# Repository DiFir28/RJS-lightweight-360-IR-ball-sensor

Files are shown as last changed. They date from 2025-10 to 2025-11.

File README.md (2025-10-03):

# RJS-lightweight-360-IR-ball-sensor

General view
Top view

## What is it for?

The RJS lightweight rules require the position of the ball emitting IR waves to be determined. 
>The ball's main emission period is 833 microseconds.

Top view

Learn more about [IR ball](https://github.com/robocup-junior/ir-golf-ball).
## Hardware solution
The sensor is a custom PCB. We use as main brain atmega2560. 24 TSSP4038 sensors are located around the circle to read the IR signal.

TSSP4038

## Software solution

Due to the time limit of the ball study period and the need for uniform reading of the circle, at 833 microseconds, data is collected by bytes of pin registers and split into specific pins in a separate cycle. Vectors are constructed based on the sensors that receive the IR signal, with the beginning in the center of the board and the end in each sensor. We calculate a vector equal to the sum of all vectors constructed before the sensors, taking into account the vector on the sensor as many times as the IR signal was detected . The desired angle to the ball will be the angle of the final vector.
The sensor readings are transmitted via the I2C protocol.

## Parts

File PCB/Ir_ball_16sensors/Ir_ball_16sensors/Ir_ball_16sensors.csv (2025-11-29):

Source: | /Users/lonelystrenger/Desktop/роботехника/vsosh/платы /Ir_ball_16sensors/Ir_ball_16sensors.kicad_sch
Date: | Tuesday 20 May 2025 at 19:58:57
Tool: | Eeschema (6.0.0-0)
Generator: | /Applications/KiCad.app/Contents/SharedSupport/plugins/bom_csv_grouped_by_value.py
Component Count: | 55
Individual Components:
Item | Qty | Reference(s) | Value | LibPart | Footprint | Datasheet
 |  | C1 | 0.1uF | Device:C | Capacitor_SMD:C_0603_1608Metric_Pad1.08x0.95mm_HandSolder | ~
 |  | C2 | 0.1uF | Device:C | Capacitor_SMD:C_0603_1608Metric_Pad1.08x0.95mm_HandSolder | ~
 |  | C3 | 47uF 10v | Device:CP1 | Capacitor_Tantalum_SMD:CP_EIA-3216-18_Kemet-A_Pad1.58x1.35mm_HandSolder
 |  | C4 | 0.1uF | Device:C | Capacitor_SMD:C_0603_1608Metric_Pad1.08x0.95mm_HandSolder | ~
 |  | C5 | 0.1uF | Device:C | Capacitor_SMD:C_0603_1608Metric_Pad1.08x0.95mm_HandSolder | ~
 |  | D1 | KP-1608SGC | Device:LED | LED_SMD:LED_0603_1608Metric_Pad1.05x0.95mm_HandSolder | ~
 |  | D2 | WS2812B | LED:WS2812B | LED_SMD:WS2812 | https://cdn-shop.adafruit.com/datasheets/WS2812B.pdf
 |  | D3 | WS2812B | LED:WS2812B | LED_SMD:WS2812 | https://cdn-shop.adafruit.com/datasheets/WS2812B.pdf
 |  | D4 | WS2812B | LED:WS2812B | LED_SMD:WS2812 | https://cdn-shop.adafruit.com/datasheets/WS2812B.pdf
 |  | D5 | WS2812B | LED:WS2812B | LED_SMD:WS2812 | https://cdn-shop.adafruit.com/datasheets/WS2812B.pdf
 |  | D6 | WS2812B | LED:WS2812B | LED_SMD:WS2812 | https://cdn-shop.adafruit.com/datasheets/WS2812B.pdf
 |  | D7 | WS2812B | LED:WS2812B | LED_SMD:WS2812 | https://cdn-shop.adafruit.com/datasheets/WS2812B.pdf
 |  | D8 | WS2812B | LED:WS2812B | LED_SMD:WS2812 | https://cdn-shop.adafruit.com/datasheets/WS2812B.pdf
 |  | D9 | WS2812B | LED:WS2812B | LED_SMD:WS2812 | https://cdn-shop.adafruit.com/datasheets/WS2812B.pdf
 |  | D10 | WS2812B | LED:WS2812B | LED_SMD:WS2812 | https://cdn-shop.adafruit.com/datasheets/WS2812B.pdf
 |  | D11 | WS2812B | LED:WS2812B | LED_SMD:WS2812 | https://cdn-shop.adafruit.com/datasheets/WS2812B.pdf
 |  | D12 | WS2812B | LED:WS2812B | LED_SMD:WS2812 | https://cdn-shop.adafruit.com/datasheets/WS2812B.pdf
 |  | D13 | WS2812B | LED:WS2812B | LED_SMD:WS2812 | https://cdn-shop.adafruit.com/datasheets/WS2812B.pdf
 |  | D14 | WS2812B | LED:WS2812B | LED_SMD:WS2812 | https://cdn-shop.adafruit.com/datasheets/WS2812B.pdf
 |  | D15 | WS2812B | LED:WS2812B | LED_SMD:WS2812 | https://cdn-shop.adafruit.com/datasheets/WS2812B.pdf
 |  | D16 | WS2812B | LED:WS2812B | LED_SMD:WS2812 | https://cdn-shop.adafruit.com/datasheets/WS2812B.pdf
 |  | D17 | WS2812B | LED:WS2812B | LED_SMD:WS2812 | https://cdn-shop.adafruit.com/datasheets/WS2812B.pdf
 |  | J1 | Conn_01x05_Male | Connector:Conn_01x05_Male | Connector_PinHeader_2.54mm:PinHeader_1x05_P2.54mm_Vertical | ~
 |  | J2 | Conn_02x03_Odd_Even | Connector_Generic:Conn_02x03_Odd_Even | Connector_PinSocket_2.54mm:PinSocket_2x03_P2.54mm_Vertical | ~
 |  | J3 | I2c | Connector:Conn_01x04_Female | Connector_PinHeader_2.54mm:PinHeader_1x04_P2.54mm_Vertical | ~
 |  | JP1 | SolderJumper_2_Open | Jumper:SolderJumper_2_Open | Jumper:SolderJumper-2_P1.3mm_Open_TrianglePad1.0x1.5mm | ~
 |  | JP2 | SolderJumper_2_Open | Jumper:SolderJumper_2_Open | Jumper:SolderJumper-2_P1.3mm_Open_TrianglePad1.0x1.5mm | ~
 |  | JP3 | SolderJumper_2_Open | Jumper:SolderJumper_2_Open | Jumper:SolderJumper-2_P1.3mm_Open_TrianglePad1.0x1.5mm | ~
 |  | R1 | 330R | Device:R | Resistor_SMD:R_0603_1608Metric_Pad0.98x0.95mm_HandSolder | ~
 |  | R2 | 10k | Device:R | Resistor_SMD:R_0603_1608Metric_Pad0.98x0.95mm_HandSolder | ~
 |  | R3 | 10k | Device:R | Resistor_SMD:R_0603_1608Metric_Pad0.98x0.95mm_HandSolder | ~
 |  | SW1 | SW_DIP_x02 | Switch:SW_DIP_x02 | Button_Switch_SMD:SW_DIP_SPSTx02_Slide_KingTek_DSHP02TS_W7.62mm_P1.27mm | ~
 |  | SW2 | SW_SPST | Switch:SW_SPST | Button_Switch_SMD:SW_SPST_PTS645 | ~
 |  | TP1 | TestPoint | Connector:TestPoint | TestPoint:TestPoint_Plated_Hole_D3.0mm | ~
 |  | TP2 | TestPoint | Connector:TestPoint | TestPoint:TestPoint_Plated_Hole_D3.0mm | ~
 |  | TP3 | TestPoint | Connector:TestPoint | TestPoint:TestPoint_Plated_Hole_D3.0mm | ~
 |  | TP4 | TestPoint | Connector:TestPoint | TestPoint:TestPoint_Plated_Hole_D3.0mm | ~
 |  | U1 | ATmega328P-M | MCU_Microchip_ATmega:ATmega328P-M | Package_DFN_QFN:QFN-32-1EP_5x5mm_P0.5mm_EP3.1x3.1mm | http://ww1.microchip.com/downloads/en/DeviceDoc/ATmega328_P%20AVR%20MCU%20with%20picoPower%20Technology%20Data%20Sheet%2040001984A.pdf
 |  | U2 | TSSP4038SS1XB | Sensor_Proximity:TSSP58038SS1XB | OptoDevice:Vishay_MINICAST-3Pin | http://www.vishay.com/docs/82740/tssp58038ss1xb.pdf
 |  | U3 | TSSP4038SS1XB | Sensor_Proximity:TSSP58038SS1XB | OptoDevice:Vishay_MINICAST-3Pin | http://www.vishay.com/docs/82740/tssp58038ss1xb.pdf
 |  | U4 | TSSP4038SS1XB | Sensor_Proximity:TSSP58038SS1XB | OptoDevice:Vishay_MINICAST-3Pin | http://www.vishay.com/docs/82740/tssp58038ss1xb.pdf
 |  | U5 | TSSP4038SS1XB | Sensor_Proximity:TSSP58038SS1XB | OptoDevice:Vishay_MINICAST-3Pin | http://www.vishay.com/docs/82740/tssp58038ss1xb.pdf
 |  | U6 | TSSP4038SS1XB | Sensor_Proximity:TSSP58038SS1XB | OptoDevice:Vishay_MINICAST-3Pin | http://www.vishay.com/docs/82740/tssp58038ss1xb.pdf
 |  | U7 | TSSP4038SS1XB | Sensor_Proximity:TSSP58038SS1XB | OptoDevice:Vishay_MINICAST-3Pin | http://www.vishay.com/docs/82740/tssp58038ss1xb.pdf
 |  | U8 | TSSP4038SS1XB | Sensor_Proximity:TSSP58038SS1XB | OptoDevice:Vishay_MINICAST-3Pin | http://www.vishay.com/docs/82740/tssp58038ss1xb.pdf
 |  | U9 | TSSP4038SS1XB | Sensor_Proximity:TSSP58038SS1XB | OptoDevice:Vishay_MINICAST-3Pin | http://www.vishay.com/docs/82740/tssp58038ss1xb.pdf
 |  | U10 | TSSP4038SS1XB | Sensor_Proximity:TSSP58038SS1XB | OptoDevice:Vishay_MINICAST-3Pin | http://www.vishay.com/docs/82740/tssp58038ss1xb.pdf
 |  | U11 | TSSP4038SS1XB | Sensor_Proximity:TSSP58038SS1XB | OptoDevice:Vishay_MINICAST-3Pin | http://www.vishay.com/docs/82740/tssp58038ss1xb.pdf
 |  | U12 | TSSP4038SS1XB | Sensor_Proximity:TSSP58038SS1XB | OptoDevice:Vishay_MINICAST-3Pin | http://www.vishay.com/docs/82740/tssp58038ss1xb.pdf
 |  | U13 | TSSP4038SS1XB | Sensor_Proximity:TSSP58038SS1XB | OptoDevice:Vishay_MINICAST-3Pin | http://www.vishay.com/docs/82740/tssp58038ss1xb.pdf
 |  | U14 | TSSP4038SS1XB | Sensor_Proximity:TSSP58038SS1XB | OptoDevice:Vishay_MINICAST-3Pin | http://www.vishay.com/docs/82740/tssp58038ss1xb.pdf
 |  | U15 | TSSP4038SS1XB | Sensor_Proximity:TSSP58038SS1XB | OptoDevice:Vishay_MINICAST-3Pin | http://www.vishay.com/docs/82740/tssp58038ss1xb.pdf
 |  | U16 | TSSP4038SS1XB | Sensor_Proximity:TSSP58038SS1XB | OptoDevice:Vishay_MINICAST-3Pin | http://www.vishay.com/docs/82740/tssp58038ss1xb.pdf
 |  | U17 | TSSP4038SS1XB | Sensor_Proximity:TSSP58038SS1XB | OptoDevice:Vishay_MINICAST-3Pin | http://www.vishay.com/docs/82740/tssp58038ss1xb.pdf
 |  | Y1 | Resonator | Device:Resonator_Small | Crystal:Resonator_SMD_Murata_CSTxExxV-3Pin_3.0x1.1mm_HandSoldering | ~
Collated Components:
Item | Qty | Reference(s) | Value | LibPart | Footprint | Datasheet
1 | 4 | C1, C2, C4, C5 | 0.1uF | Device:C | Capacitor_SMD:C_0603_1608Metric_Pad1.08x0.95mm_HandSolder | ~
2 | 1 | C3 | 47uF 10v | Device:CP1 | Capacitor_Tantalum_SMD:CP_EIA-3216-18_Kemet-A_Pad1.58x1.35mm_HandSolder
3 | 1 | D1 | KP-1608SGC | Device:LED | LED_SMD:LED_0603_1608Metric_Pad1.05x0.95mm_HandSolder | ~
4 | 16 | D2, D3, D4, D5, D6, D7, D8, D9, D10, D11, D12, D13, D14, D15, D16, D17 | WS2812B | LED:WS2812B | LED_SMD:WS2812 | https://cdn-shop.adafruit.com/datasheets/WS2812B.pdf
5 | 1 | J1 | Conn_01x05_Male | Connector:Conn_01x05_Male | Connector_PinHeader_2.54mm:PinHeader_1x05_P2.54mm_Vertical | ~
6 | 1 | J2 | Conn_02x03_Odd_Even | Connector_Generic:Conn_02x03_Odd_Even | Connector_PinSocket_2.54mm:PinSocket_2x03_P2.54mm_Vertical | ~
7 | 1 | J3 | I2c | Connector:Conn_01x04_Female | Connector_PinHeader_2.54mm:PinHeader_1x04_P2.54mm_Vertical | ~
8 | 3 | JP1, JP2, JP3 | SolderJumper_2_Open | Jumper:SolderJumper_2_Open | Jumper:SolderJumper-2_P1.3mm_Open_TrianglePad1.0x1.5mm | ~
9 | 1 | R1 | 330R | Device:R | Resistor_SMD:R_0603_1608Metric_Pad0.98x0.95mm_HandSolder | ~
10 | 2 | R2, R3 | 10k | Device:R | Resistor_SMD:R_0603_1608Metric_Pad0.98x0.95mm_HandSolder | ~
11 | 1 | SW1 | SW_DIP_x02 | Switch:SW_DIP_x02 | Button_Switch_SMD:SW_DIP_SPSTx02_Slide_KingTek_DSHP02TS_W7.62mm_P1.27mm | ~
12 | 1 | SW2 | SW_SPST | Switch:SW_SPST | Button_Switch_SMD:SW_SPST_PTS645 | ~
13 | 4 | TP1, TP2, TP3, TP4 | TestPoint | Connector:TestPoint | TestPoint:TestPoint_Plated_Hole_D3.0mm | ~
14 | 1 | U1 | ATmega328P-M | MCU_Microchip_ATmega:ATmega328P-M | Package_DFN_QFN:QFN-32-1EP_5x5mm_P0.5mm_EP3.1x3.1mm | http://ww1.microchip.com/downloads/en/DeviceDoc/ATmega328_P%20AVR%20MCU%20with%20picoPower%20Technology%20Data%20Sheet%2040001984A.pdf
15 | 16 | U2, U3, U4, U5, U6, U7, U8, U9, U10, U11, U12, U13, U14, U15, U16, U17 | TSSP4038SS1XB | Sensor_Proximity:TSSP58038SS1XB | OptoDevice:Vishay_MINICAST-3Pin | http://www.vishay.com/docs/82740/tssp58038ss1xb.pdf
16 | 1 | Y1 | Resonator | Device:Resonator_Small | Crystal:Resonator_SMD_Murata_CSTxExxV-3Pin_3.0x1.1mm_HandSoldering | ~

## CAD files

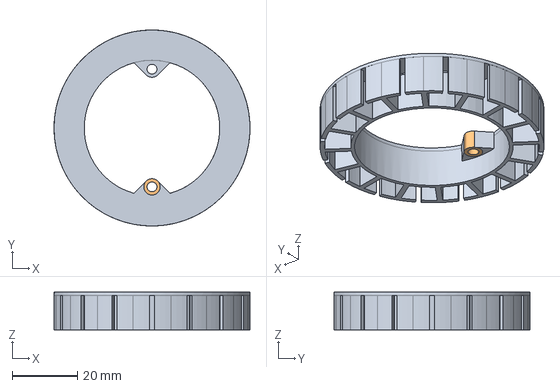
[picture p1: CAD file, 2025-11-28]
3D_models/Ir_ball_16sensors.step
60.0 x 60.0 x 11.6 mm

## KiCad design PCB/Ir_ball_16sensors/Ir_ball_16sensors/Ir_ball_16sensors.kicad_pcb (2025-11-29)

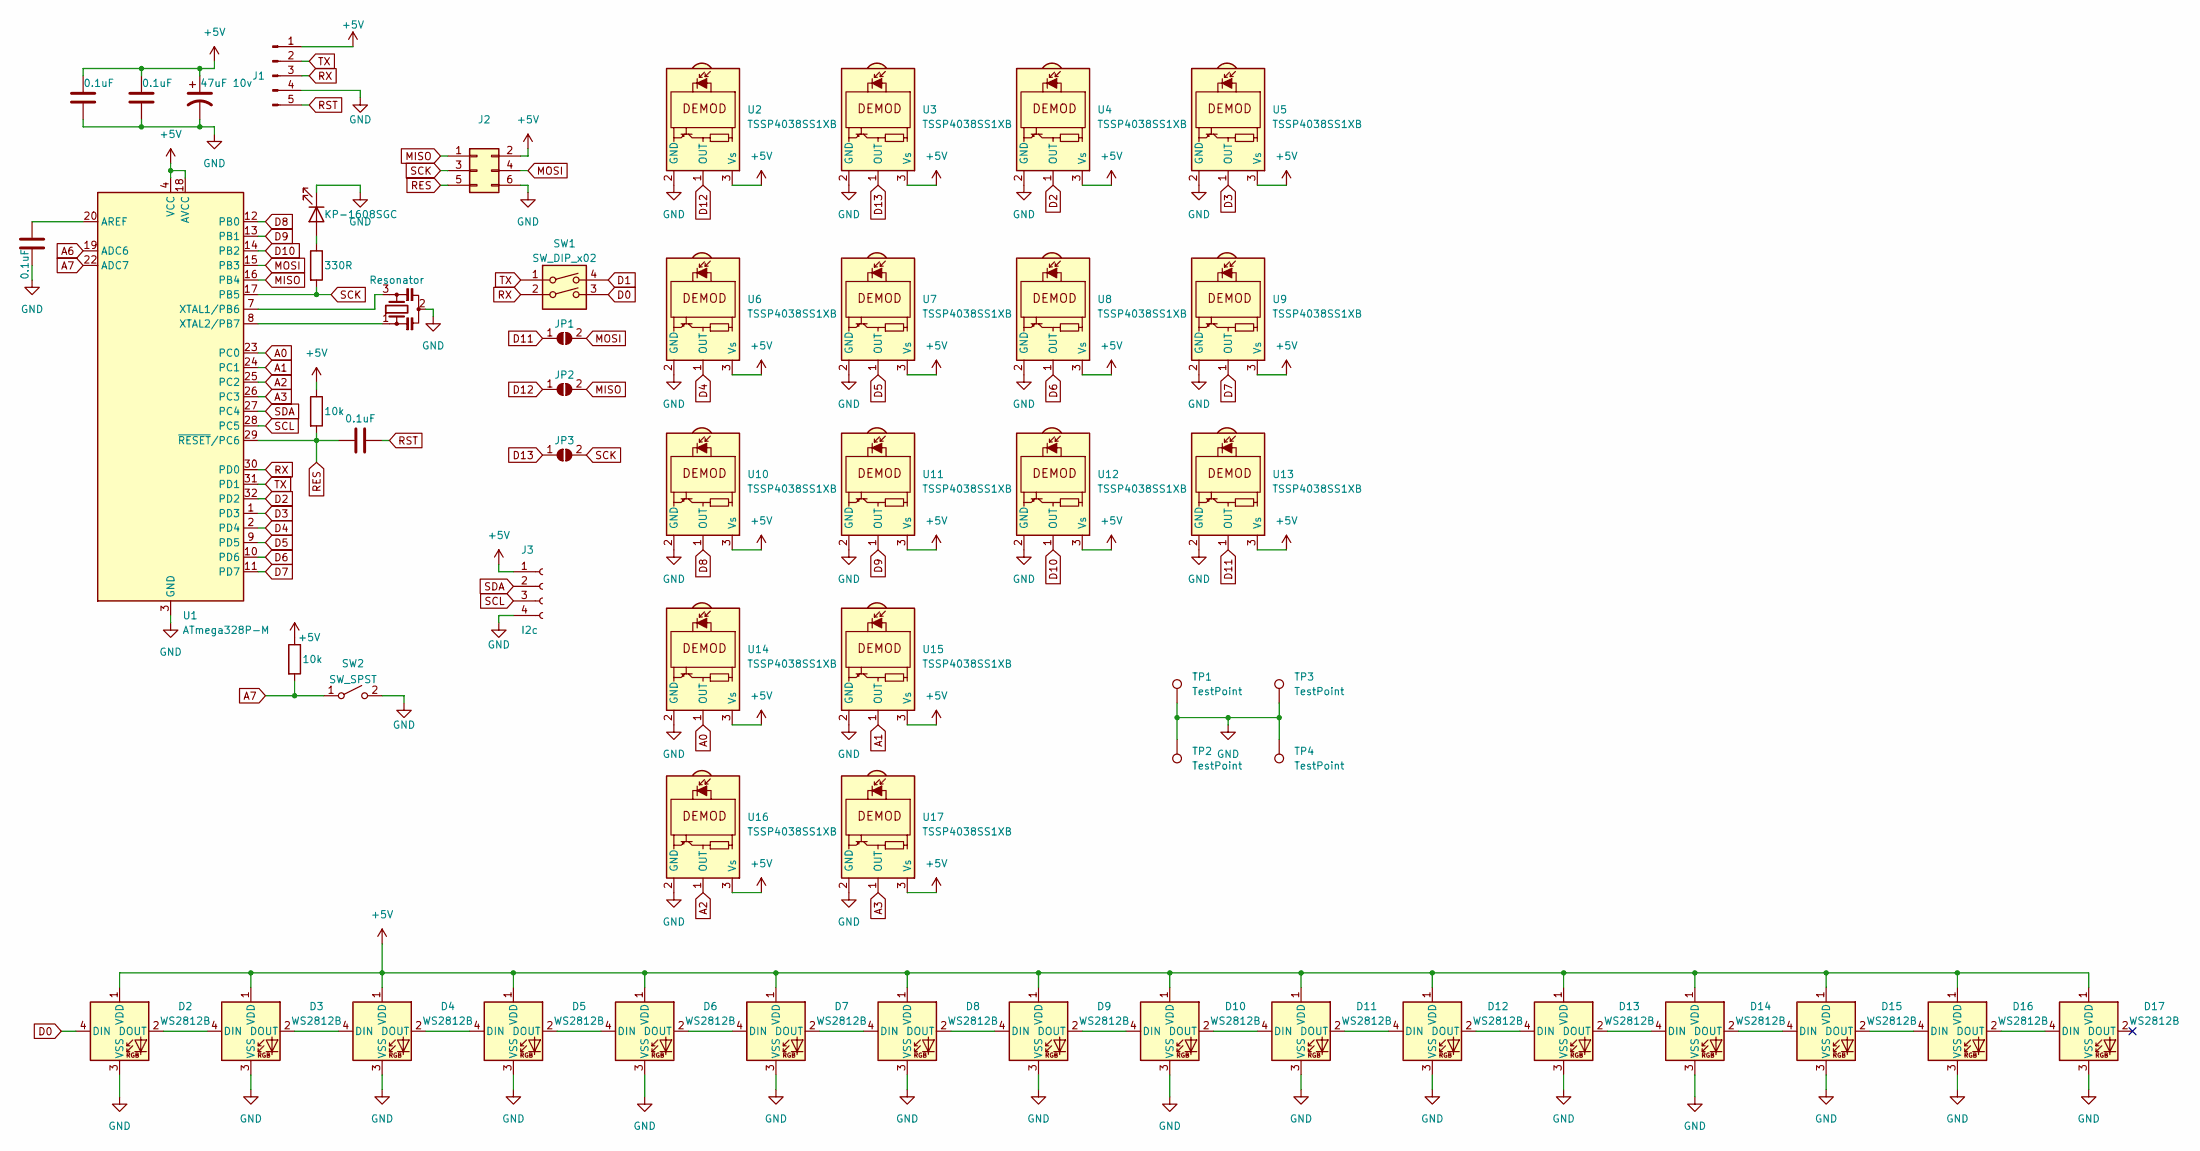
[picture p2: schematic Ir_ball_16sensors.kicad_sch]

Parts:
C1, C2, C4, C5: 0.1uF; C_0603_1608Metric_Pad1.08x0.95mm_HandSolder
C3: 47uF 10v; CP_EIA-3216-18_Kemet-A_Pad1.58x1.35mm_HandSolder
D1: KP-1608SGC; LED_0603_1608Metric_Pad1.05x0.95mm_HandSolder
D2, D3, D4, D5, D6, D7, D8, D9, D10, D11, D12, D13, D14, D15, D16, D17: WS2812B; WS2812
J1: Conn_01x05_Male; PinHeader_1x05_P2.54mm_Vertical
J2: Conn_02x03_Odd_Even; PinSocket_2x03_P2.54mm_Vertical
J3: I2c; PinHeader_1x04_P2.54mm_Vertical
JP1, JP2, JP3: SolderJumper_2_Open; SolderJumper-2_P1.3mm_Open_TrianglePad1.0x1.5mm
R1: 330R; R_0603_1608Metric_Pad0.98x0.95mm_HandSolder
R2, R3: 10k; R_0603_1608Metric_Pad0.98x0.95mm_HandSolder
SW1: SW_DIP_x02; SW_DIP_SPSTx02_Slide_KingTek_DSHP02TS_W7.62mm_P1.27mm
SW2: SW_SPST; SW_SPST_PTS645
TP1, TP2, TP3, TP4: TestPoint; TestPoint_Plated_Hole_D3.0mm
U1: ATmega328P-M; QFN-32-1EP_5x5mm_P0.5mm_EP3.1x3.1mm
U2, U3, U4, U5, U6, U7, U8, U9, U10, U11, U12, U13, U14, U15, U16, U17: TSSP4038SS1XB; Vishay_MINICAST-3Pin
Y1: Resonator; Resonator_SMD_Murata_CSTxExxV-3Pin_3.0x1.1mm_HandSoldering

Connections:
+5V: C1.2, C2.2, C3.1, D2.1 (VDD), D3.1 (VDD), D4.1 (VDD), D5.1 (VDD), D6.1 (VDD), D7.1 (VDD), D8.1 (VDD), D9.1 (VDD), D10.1 (VDD), D11.1 (VDD), D12.1 (VDD), D13.1 (VDD), D14.1 (VDD), D15.1 (VDD), D16.1 (VDD), D17.1 (VDD), J1.1, J2.2, J3.1, R2.1, R3.1, U1.4 (VCC), U1.6 (VCC), U1.18 (AVCC), U2.3 (Vs), U3.3 (Vs), U4.3 (Vs), U5.3 (Vs), U6.3 (Vs), U7.3 (Vs), U8.3 (Vs), U9.3 (Vs), U10.3 (Vs), U11.3 (Vs), U12.3 (Vs), U13.3 (Vs), U14.3 (Vs), U15.3 (Vs), U16.3 (Vs), U17.3 (Vs)
A0: U1.23 (PC0), U14.1 (OUT)
A1: U1.24 (PC1), U15.1 (OUT)
A2: U1.25 (PC2), U16.1 (OUT)
A3: U1.26 (PC3), U17.1 (OUT)
A6: U1.19 (ADC6)
A7: R3.2, SW2.1 (A), U1.22 (ADC7)
D0: D2.4 (DIN), SW1.3
D1: SW1.4
D2: U1.32 (PD2), U4.1 (OUT)
D3: U1.1 (PD3), U5.1 (OUT)
D4: U1.2 (PD4), U6.1 (OUT)
D5: U1.9 (PD5), U7.1 (OUT)
D6: U1.10 (PD6), U8.1 (OUT)
D7: U1.11 (PD7), U9.1 (OUT)
D8: U1.12 (PB0), U10.1 (OUT)
D9: U1.13 (PB1), U11.1 (OUT)
D10: U1.14 (PB2), U12.1 (OUT)
D11: JP1.1 (A), U13.1 (OUT)
D12: JP2.1 (A), U2.1 (OUT)
D13: JP3.1 (A), U3.1 (OUT)
GND: C1.1, C2.1, C3.2, C5.1, D1.1 (K), D2.3 (VSS), D3.3 (VSS), D4.3 (VSS), D5.3 (VSS), D6.3 (VSS), D7.3 (VSS), D8.3 (VSS), D9.3 (VSS), D10.3 (VSS), D11.3 (VSS), D12.3 (VSS), D13.3 (VSS), D14.3 (VSS), D15.3 (VSS), D16.3 (VSS), D17.3 (VSS), J1.4, J2.6, J3.4, SW2.2 (B), TP1.1, TP2.1, TP3.1, TP4.1, U1.3 (GND), U1.5 (GND), U1.21 (GND), U1.33 (GND), U2.2 (GND), U3.2 (GND), U4.2 (GND), U5.2 (GND), U6.2 (GND), U7.2 (GND), U8.2 (GND), U9.2 (GND), U10.2 (GND), U11.2 (GND), U12.2 (GND), U13.2 (GND), U14.2 (GND), U15.2 (GND), U16.2 (GND), U17.2 (GND), Y1.2
MISO: J2.1, JP2.2 (B), U1.16 (PB4)
MOSI: J2.4, JP1.2 (B), U1.15 (PB3)
unnamed: C5.2, U1.20 (AREF)
unnamed: D1.2 (A), R1.1
unnamed: D2.2 (DOUT), D3.4 (DIN)
unnamed: D3.2 (DOUT), D4.4 (DIN)
unnamed: D4.2 (DOUT), D5.4 (DIN)
unnamed: D5.2 (DOUT), D6.4 (DIN)
unnamed: D6.2 (DOUT), D7.4 (DIN)
unnamed: D7.2 (DOUT), D8.4 (DIN)
unnamed: D8.2 (DOUT), D9.4 (DIN)
unnamed: D10.2 (DOUT), D11.4 (DIN)
unnamed: D9.2 (DOUT), D10.4 (DIN)
unnamed: D11.2 (DOUT), D12.4 (DIN)
unnamed: D12.2 (DOUT), D13.4 (DIN)
unnamed: D13.2 (DOUT), D14.4 (DIN)
unnamed: D14.2 (DOUT), D15.4 (DIN)
unnamed: D15.2 (DOUT), D16.4 (DIN)
unnamed: D16.2 (DOUT), D17.4 (DIN)
unnamed: U1.7 (XTAL1/PB6), Y1.3
unnamed: U1.8 (XTAL2/PB7), Y1.1
RES: C4.1, J2.5, R2.2, U1.29 (~RESET/PC6)
RST: C4.2, J1.5
RX: J1.3, SW1.2, U1.30 (PD0)
SCK: J2.3, JP3.2 (B), R1.2, U1.17 (PB5)
SCL: J3.3, U1.28 (PC5)
SDA: J3.2, U1.27 (PC4)
TX: J1.2, SW1.1, U1.31 (PD1)

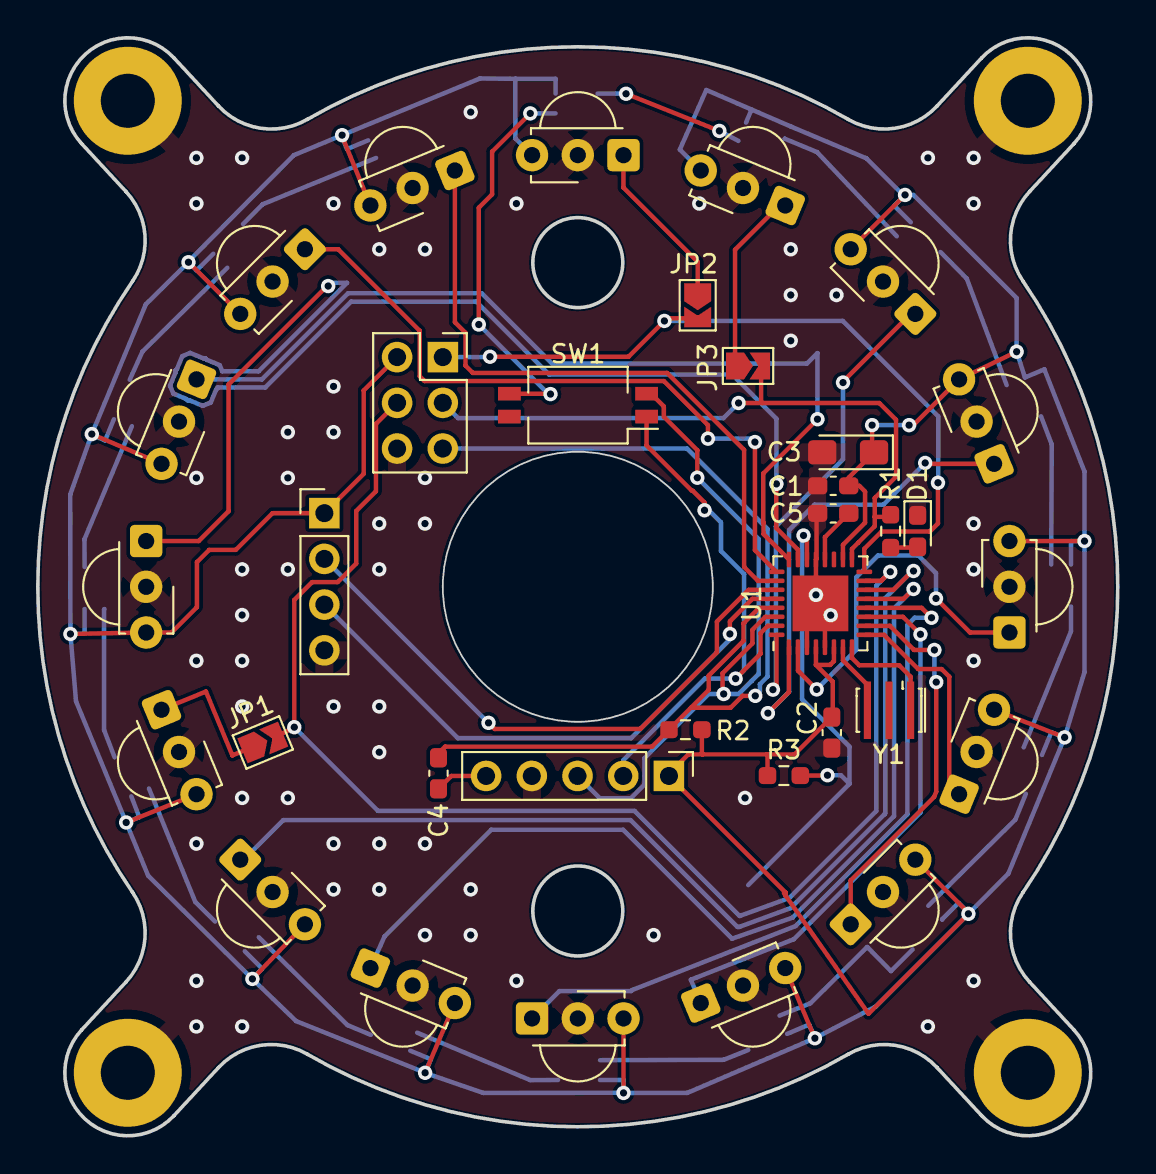
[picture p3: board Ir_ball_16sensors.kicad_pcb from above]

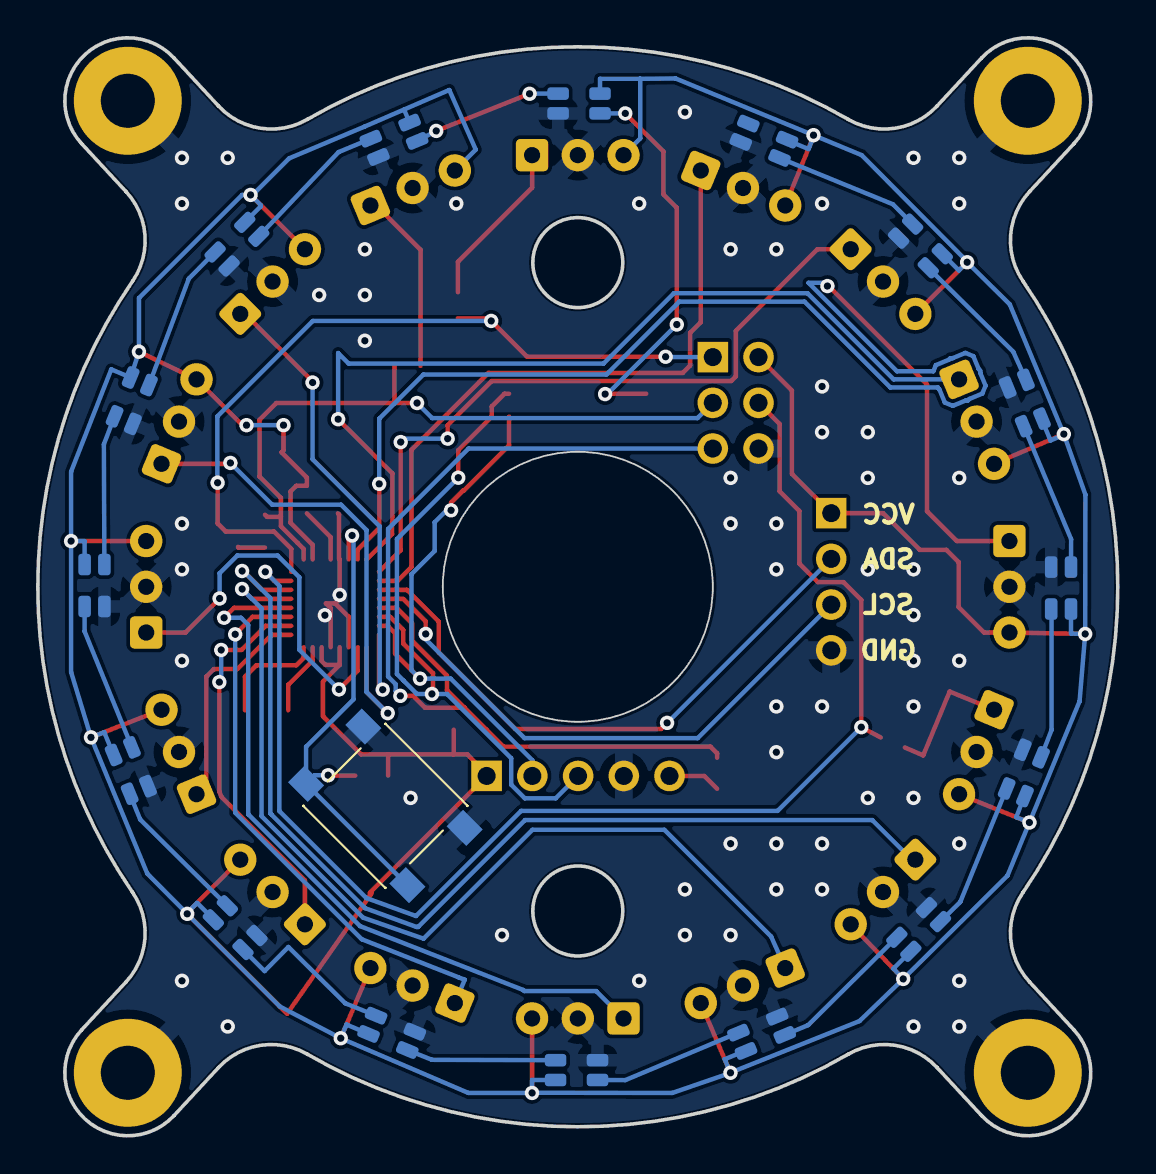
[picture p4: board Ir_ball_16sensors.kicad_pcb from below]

Board: 2 copper layers, 60.0 x 61.0 mm, 55 parts (17 on the bottom side), 48 nets.

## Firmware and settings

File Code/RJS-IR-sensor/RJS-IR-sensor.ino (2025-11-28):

#include <Arduino.h>
#include <Wire.h>

#define printf(x) Serial.print(x);
#define printfs(x) Serial.print(x); Serial.print(" ");
#define printflt(x) Serial.print(x); Serial.print("\t");
#define printfln(x) Serial.println(x);

int SensorPins[] = {4,3,2,13,  12,A3,A2,A1,  A0,11,10,9,  8,7,6,5   };
int rersensorpins[] = {20,19,18,5,  4,11,10,9,  8,3,2,1,  0,23,22,21 };
int err_pins[] = {0,0,0,1,  0,0,0,0,  0,0,0,0,  0,0,0,0}; 
int readEE[16] = {0};
unsigned long raw_valueBCD[300] = {0};

short ir, rast = 0, qrast = 0, max_ = 0;
double cos_side, sin_side;
float angle = 0;
int data[2];
unsigned long pind = 0,  one = 1;

float _err_measure = 3;  
float _q = 0.2;   

int b = 12, max_i  = 0;
float a = 0;

float simpleKalman(float newVal) {
  float _kalman_gain, _current_estimate;
  static float _err_estimate = _err_measure;
  static float _last_estimate;
  _kalman_gain = (float)_err_estimate / (_err_estimate + _err_measure);
  _current_estimate = _last_estimate + (float)_kalman_gain * (newVal - _last_estimate);
  _err_estimate =  (1.0 - _kalman_gain) * _err_estimate + fabs(_last_estimate - _current_estimate) * _q;
  _last_estimate = _current_estimate;
  return _current_estimate;
}


void sendData() {
  Wire.write((byte*) &data, 2 * sizeof(int));

}

void setup() {
  Serial.begin(115200);
  Wire.begin(0x09);
  Wire.onRequest(sendData);
  for (int i = 0; i < 16; ++i) {
    pinMode(SensorPins[i], INPUT);
  }
  for (int i = 0; i < 16; i++) {
    readEE[0] = 0;
  }

}

void loop() {
  
  cos_side = 0, sin_side = 0, rast = 0, max_ =  0;
  ir = 0;

  unsigned long startTime_us = micros() ;

  pind = PIND;
  raw_valueBCD [ir] = PINB + (PINC << 8 + (pind << 16);
  startTime_us = micros() ;

  while ((micros() - startTime_us) < 833*2) {
    pind = PIND;
    raw_valueBCD [ir] = PINB + (PINC << 8 + (pind << 16);
    ir += 1;
  }


  for (int i = 0; i < 16; i++) {
    int shift = rersensorpins[i];
    for (int j = 0; j < ir-1; j++) {
      readEE[i] += ((raw_valueBCD[j] & (one << shift)) == 0);
    }
  }


  int rett = 0;
  for (int i = 0; i < 16; i++) {
    if (err_pins[i]){
      continue;
    }
    rett += (readEE[i] > 0);
    cos_side += (cos(i * 15.0 * 3.1415926 / 180.0) * readEE[i]  * 100 );
    sin_side += (sin(i * 15.0 * 3.1415926 / 180.0) * readEE[i] * 100 );
    if (readEE[i] > max_) {
      max_ = max(max_, readEE[i]);
      max_i = i;
    }
  }


  printflt(ir);
  angle = simpleKalman((atan2(sin_side, cos_side) * 180 / 3.1415));
  printflt(angle);
  

  for (int i = 0; i < 16; i++) {
    printfs(readEE[i]);
    readEE[i] = 0;
  }
  for (int i = 0; i < ir+1; i++) {
    raw_valueBCD [i] = 0;
  }

  
  if (rett  == 0) {
    data[0] = 999;
    data[1] = -1;
  } else {
    data[0] = angle;
    data[1] = a * 100;
  }


  printfln("");
}

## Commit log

2025-11-28 Update struct of repository
    [Ir_ball_16sensors.step]
2025-11-29 Add pcb
    [Ir_ball_16sensors.csv, Ir_ball_16sensors.kicad_pcb, Ir_ball_16sensors.kicad_sch]
